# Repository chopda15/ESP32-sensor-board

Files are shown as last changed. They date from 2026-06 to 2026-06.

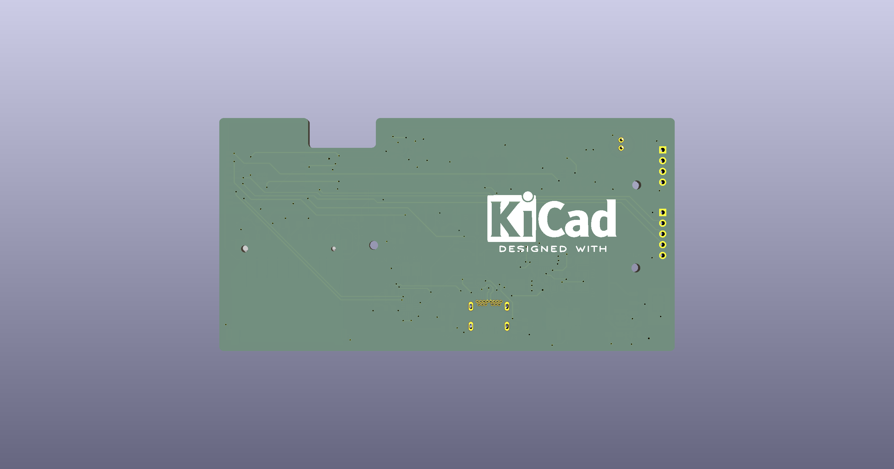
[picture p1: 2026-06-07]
3D_image/ESP32-sensor-board_3D_back.png

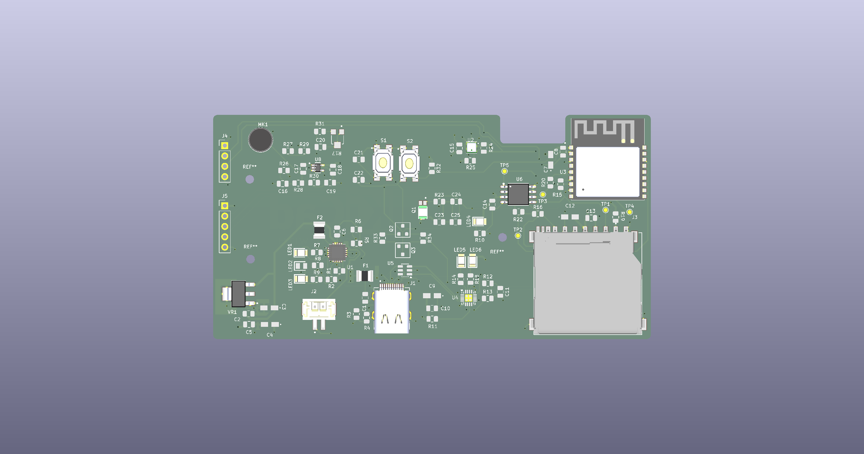
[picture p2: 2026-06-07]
3D_image/ESP32-sensor-board_3D_front.png

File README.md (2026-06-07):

# ESP32-C3 IoT Sensor Board with Li-ion Power Management

Custom-designed IoT PCB built in KiCad featuring the ESP32-C3-WROOM-02 module, integrated Li-ion charging circuitry, environmental sensing, onboard storage, and USB-C connectivity.

This project was developed to practice real-world embedded hardware design workflows including schematic capture, PCB layout, signal integrity considerations, power management, DFM validation, and manufacturing preparation.

---

# Features

## Microcontroller
- ESP32-C3-WROOM-02
- Wi-Fi + BLE connectivity
- Low-power IoT architecture

## Power System
- TP4056 Li-ion battery charger
- USB-C power input
- Single-cell LiPo battery support
- Battery charging and protection circuitry
- 3.3V regulated power rail

## Sensors & Peripherals
- BME280 environmental sensor
  - Temperature
  - Humidity
  - Pressure
- Ambient light sensor
- Sound sensor with microphone amplifier
- OLED display via I2C
- SPI flash memory
- Micro SD card interface

## User Interface
- Status LEDs
- Push buttons
- USB-UART interface for programming/debugging

---

# PCB Design Highlights

## Signal Integrity
- Differential routing for USB signals
- SPI trace optimization
- Reduced trace lengths for high-speed signals
- Ground plane implementation
- Decoupling capacitor placement optimization

## Power Distribution
- Copper pours for stable power delivery
- Wide power traces to minimize voltage drop
- Multiple decoupling capacitors for noise reduction

## Manufacturing Considerations
- ERC and DRC validation
- DFM analysis before fabrication
- Gerber generation
- BOM and centroid file generation
- Silkscreen refinement
- 3D PCB validation

---

# Tools & Technologies

- KiCad 9
- ESP32-C3
- TP4056
- JLCPCB DFM tools
- Git & GitHub

---

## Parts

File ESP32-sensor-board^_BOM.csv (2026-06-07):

Reference | Qty | Value | DNP | Exclude from BOM | Exclude from Board | Footprint | Datasheet
C1,C2,C5,C8,C10,C13,C14,C15,C16,C18,C21,C22,C23 | 13 | 0.1u |  |  |  | Capacitor_SMD:C_0805_2012Metric
C3,C4,C7,C12 | 4 | 10u |  |  |  | Footprints:T491A
C6,C11 | 2 | 1u |  |  |  | Capacitor_SMD:C_0805_2012Metric
C9 | 1 | 4.7u |  |  |  | Footprints:T491A
C17,C24,C25 | 3 | 10n |  |  |  | Capacitor_SMD:C_0805_2012Metric
C19 | 1 | 10u |  |  |  | Capacitor_SMD:C_0805_2012Metric
C20 | 1 | 100pF |  |  |  | Capacitor_SMD:C_0805_2012Metric
F1,F2 | 2 | 0ZCH0110AF2E |  |  |  | Footprints:FUSC3226X100N | https://www.belfuse.com/resources/datasheets/circuitprotection/ds-cp-0zch-series.pdf
J1 | 1 | SS-52400-002 |  |  |  | Footprints:BELFUSE_SS-52400-002
J2 | 1 | B2B-PH-SM4-TB |  |  |  | Footprints:JST_B2B-PH-SM4-TB
J3 | 1 | GSD090012SEU |  |  |  | Footprints:AMPHENOL_GSD090012SEU
J4 | 1 | Conn_01x04_Pin |  |  |  | Connector_PinHeader_2.54mm:PinHeader_1x04_P2.54mm_Vertical
J5 | 1 | Conn_01x05_Pin |  |  |  | Connector_PinHeader_2.54mm:PinHeader_1x05_P2.54mm_Vertical
LED1,LED4,LED5 | 3 | LTST-C170KRKT |  |  |  | Footprints:LEDC2012X120N | https://componentsearchengine.com/Datasheets/1/LTST-C170KRKT.pdf
LED2,LED6 | 2 | LTST-C170GKT |  |  |  | Footprints:LEDC2012X120N | https://mm.digikey.com/Volume0/opasdata/d220001/medias/docus/895/LTST-C170GKT.pdf
LED3 | 1 | LTST-C170TBKT |  |  |  | Footprints:LEDC2012X120N | https://componentsearchengine.com/Datasheets/1/LTST-C170TBKT.pdf
MK1 | 1 | CMC-5042PF-AC |  |  |  | Footprints:CUI_CMC-5042PF-AC
Q1 | 1 | TEMT6000X01 |  |  |  | Footprints:TRANS_TEMT6000X01
Q2,Q3 | 2 | BC817 |  |  |  | PCM_Package_TO_SOT_SMD_AKL:SOT-23 | https://www.tme.eu/Document/7b5ea7386544f524d0315334956093bb/BC817-16.215.pdf
R1,R2,R6,R19,R23,R32,R33,R34 | 8 | 10K |  |  |  | Resistor_SMD:R_0805_2012Metric
R3,R4 | 2 | 5.1K |  |  |  | Resistor_SMD:R_0805_2012Metric
R5,R26 | 2 | 2K |  |  |  | Resistor_SMD:R_0805_2012Metric
R7,R8,R9,R10,R14,R18 | 6 | 470 |  |  |  | Resistor_SMD:R_0805_2012Metric
R11,R30 | 2 | 1K |  |  |  | Resistor_SMD:R_0805_2012Metric
R12 | 1 | 47K5 |  |  |  | Resistor_SMD:R_0805_2012Metric
R13 | 1 | 22K1 |  |  |  | Resistor_SMD:R_0805_2012Metric
R15,R16,R20,R22 | 4 | 50 |  |  |  | Resistor_SMD:R_0805_2012Metric
R17 | 1 | 35WR100KLFTR |  |  |  | Footprints:TRIM_35WR100KLFTR
R24,R25 | 2 | 4K7 |  |  |  | Resistor_SMD:R_0805_2012Metric
R27,R28,R29 | 3 | 1M |  |  |  | Resistor_SMD:R_0805_2012Metric
R31 | 1 | 22K |  |  |  | Resistor_SMD:R_0805_2012Metric
S1,S2 | 2 | USLPT2819DT2TR |  |  |  | Footprints:SW_TL3305AF260QG
TP1 | 1 | TestMosi_DI |  |  |  | TestPoint:TestPoint_Pad_D1.0mm
TP2 | 1 | TestMiso_DI |  |  |  | TestPoint:TestPoint_Pad_D1.0mm
TP3 | 1 | Test SCLK |  |  |  | TestPoint:TestPoint_Pad_D1.0mm
TP4 | 1 | Test CS_SD |  |  |  | TestPoint:TestPoint_Pad_D1.0mm
TP5 | 1 | Test CS |  |  |  | TestPoint:TestPoint_Pad_D1.0mm
U1 | 1 | MCP73871-2CAI_ML |  |  |  | Footprints:QFN50P400X400X100-21N
U2 | 1 | BME280 |  |  |  | Footprints:PSON65P250X250X100-8N
U3 | 1 | ESP32-C3-WROOM-02-H4 |  |  |  | Footprints:MODULE_ESP32-C3-WROOM-02-H4
U4 | 1 | CP2102N-Axx-xQFN20 |  |  |  | Package_DFN_QFN:SiliconLabs_QFN-20-1EP_3x3mm_P0.5mm_EP1.8x1.8mm | https://www.silabs.com/documents/public/data-sheets/cp2102n-datasheet.pdf
U5 | 1 | USBLC6-2SC6 |  |  |  | Package_TO_SOT_SMD:SOT-23-6 | https://www.st.com/resource/en/datasheet/usblc6-2.pdf
U6 | 1 | W25Q32JVSSIQ |  |  |  | Footprints:SOIC127P790X216-8N
U8 | 1 | MAX4466EXK |  |  |  | Footprints:SOT65P210X110-5N
VR1 | 1 | LM1117MPX-3.3 |  |  |  | Footprints:VREG_LM1117MPX-3.3_NOPB

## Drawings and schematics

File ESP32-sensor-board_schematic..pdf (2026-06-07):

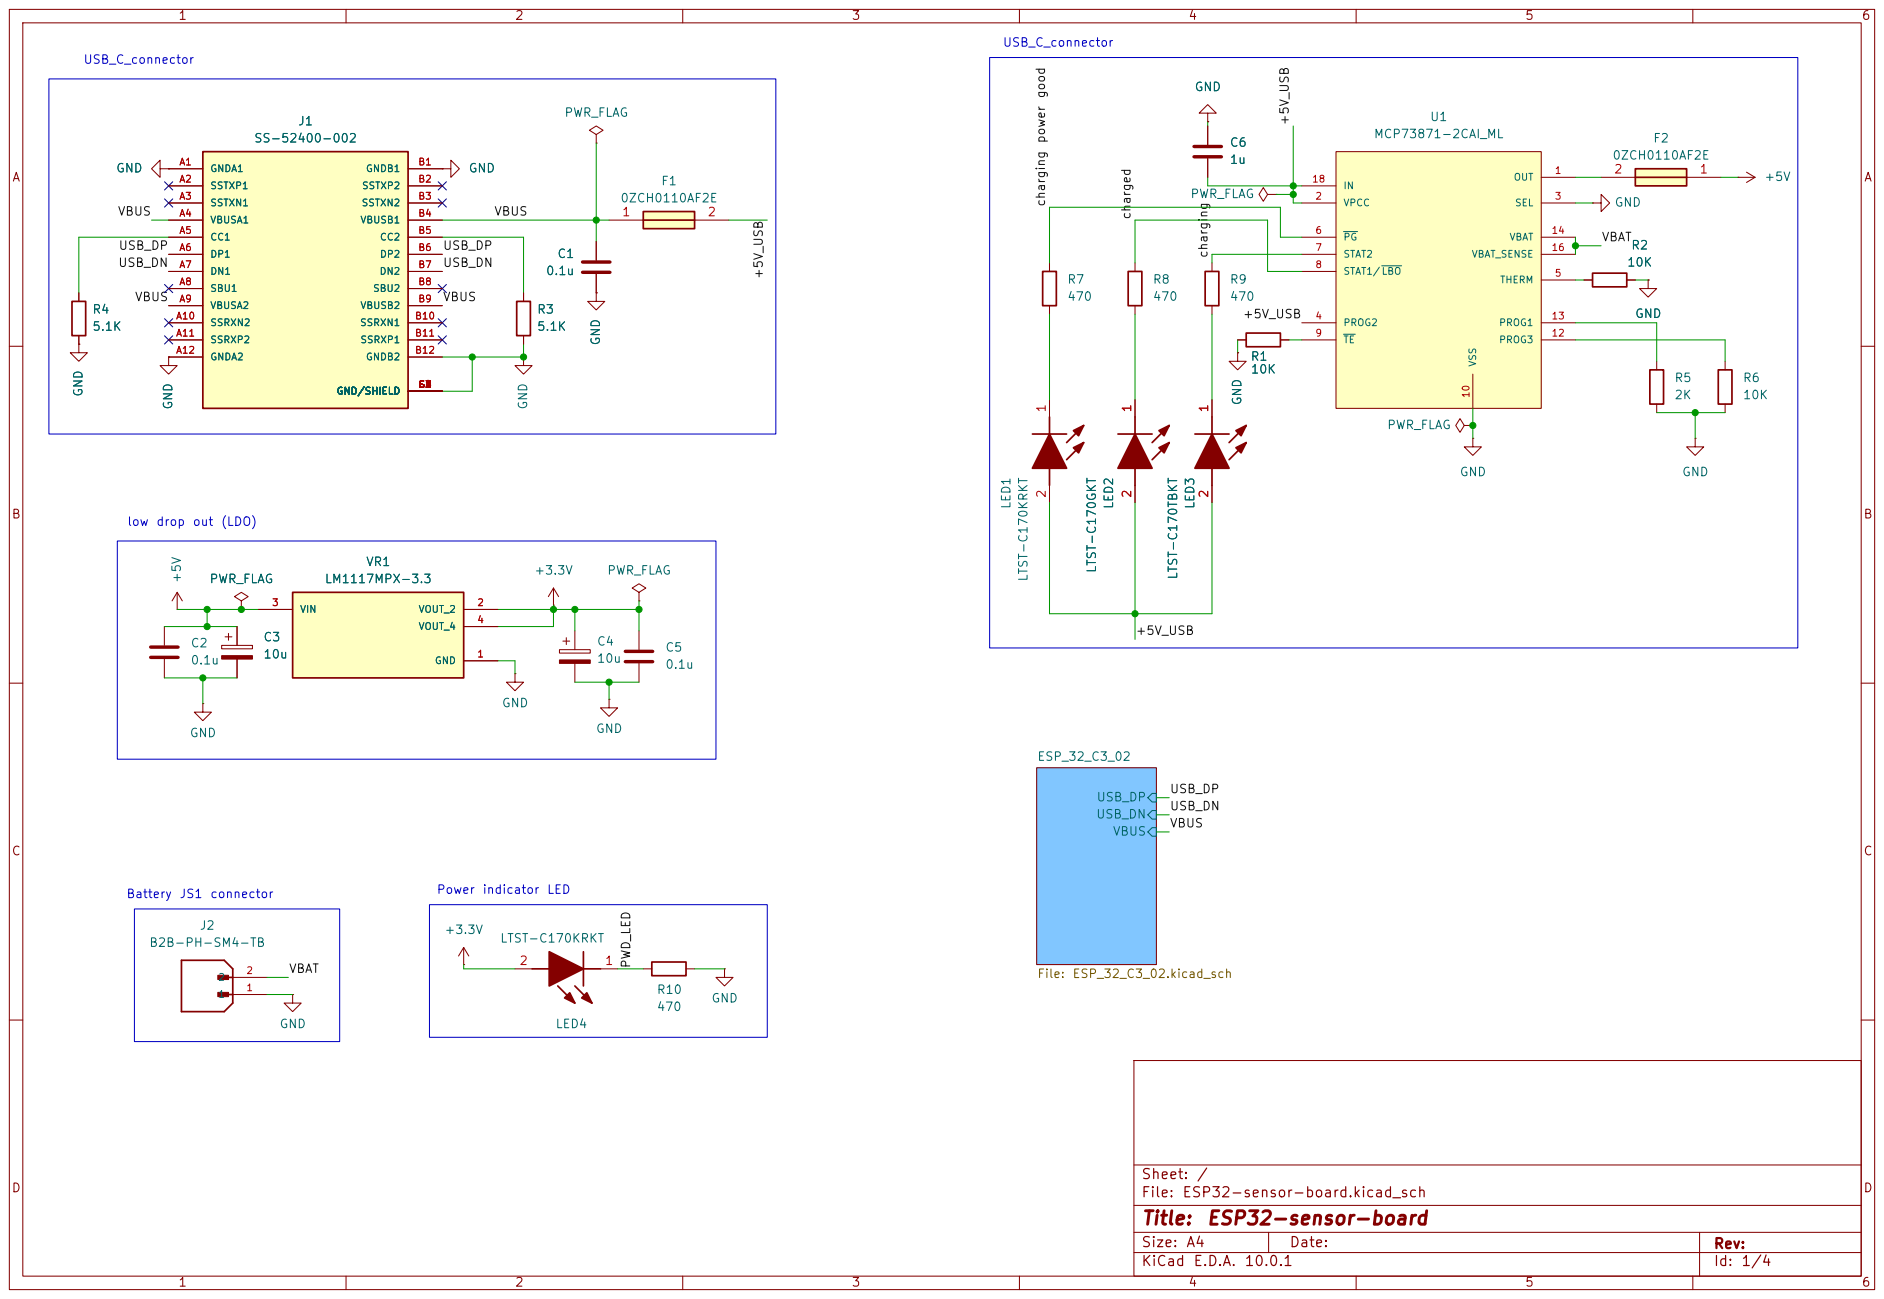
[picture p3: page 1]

low drop out (LDO) USB_C_connector Battery JS1 connector GND

VBUS Power indicator LED

Size: A4 | Rev:
KiCad E.D.A. 10.0.1 | Id: 1/4

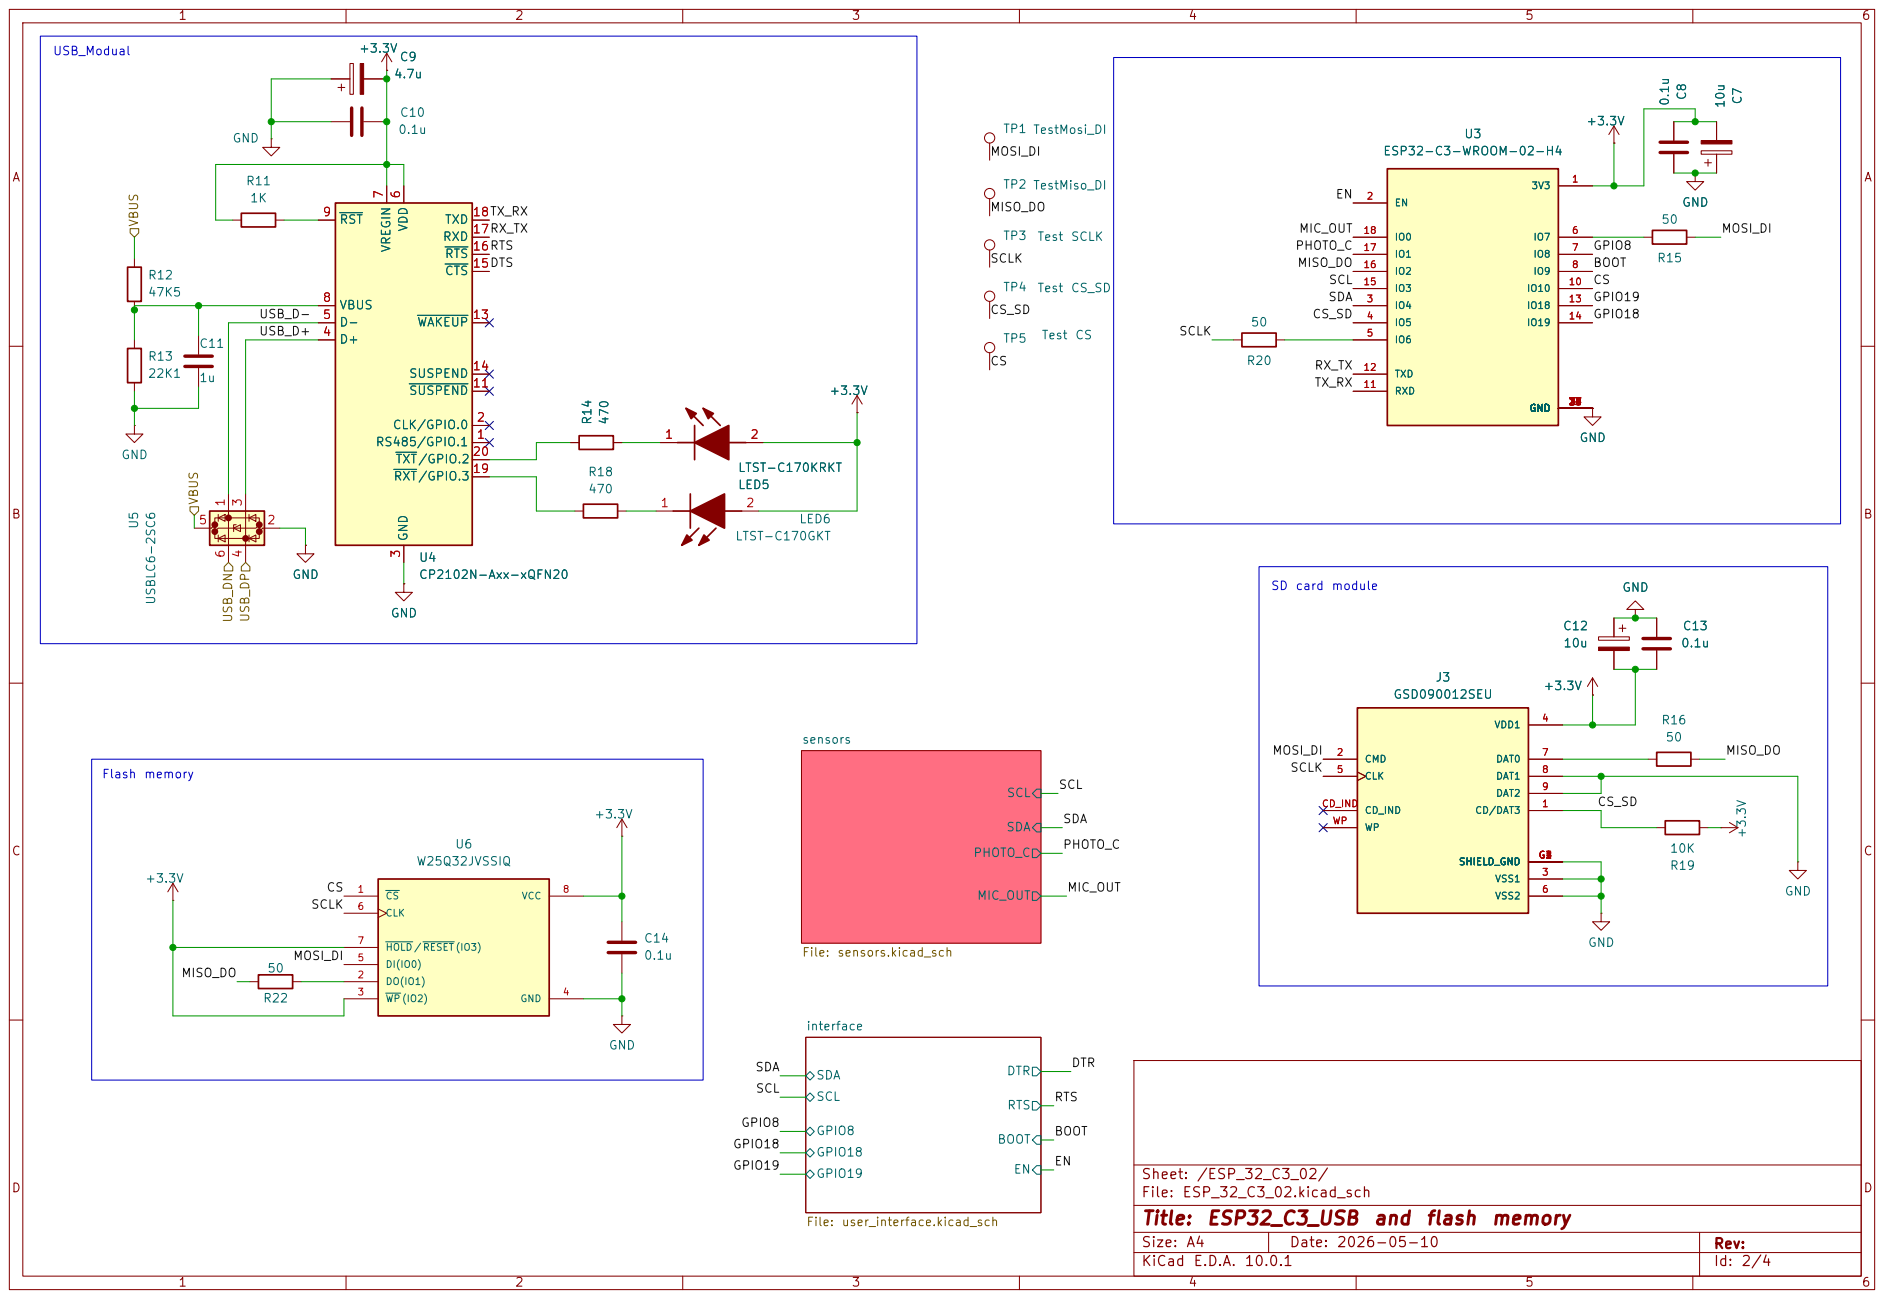
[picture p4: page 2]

Sheet: /ESP_32_C3_02/
File: ESP_32_C3_02.kicad_sch
Title: ESP32_C3_USB and flash memory

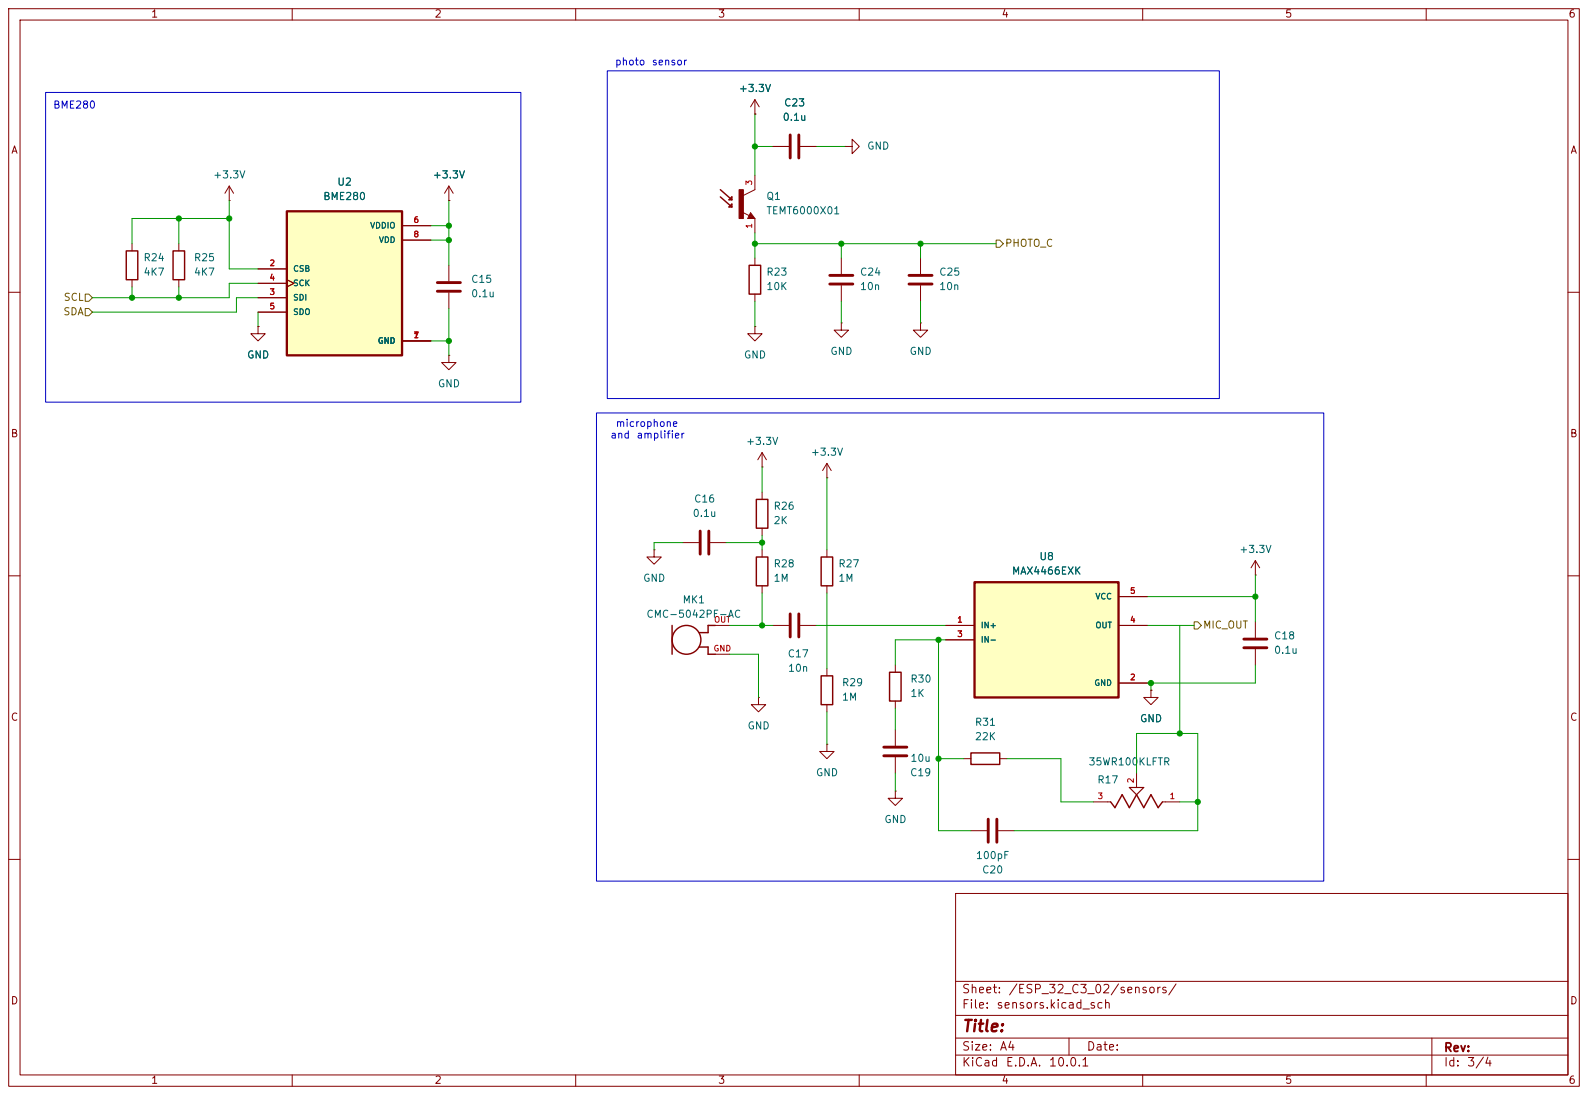
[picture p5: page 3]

GND OUT MK1 CMC-5042PF-AC +3.3V GND

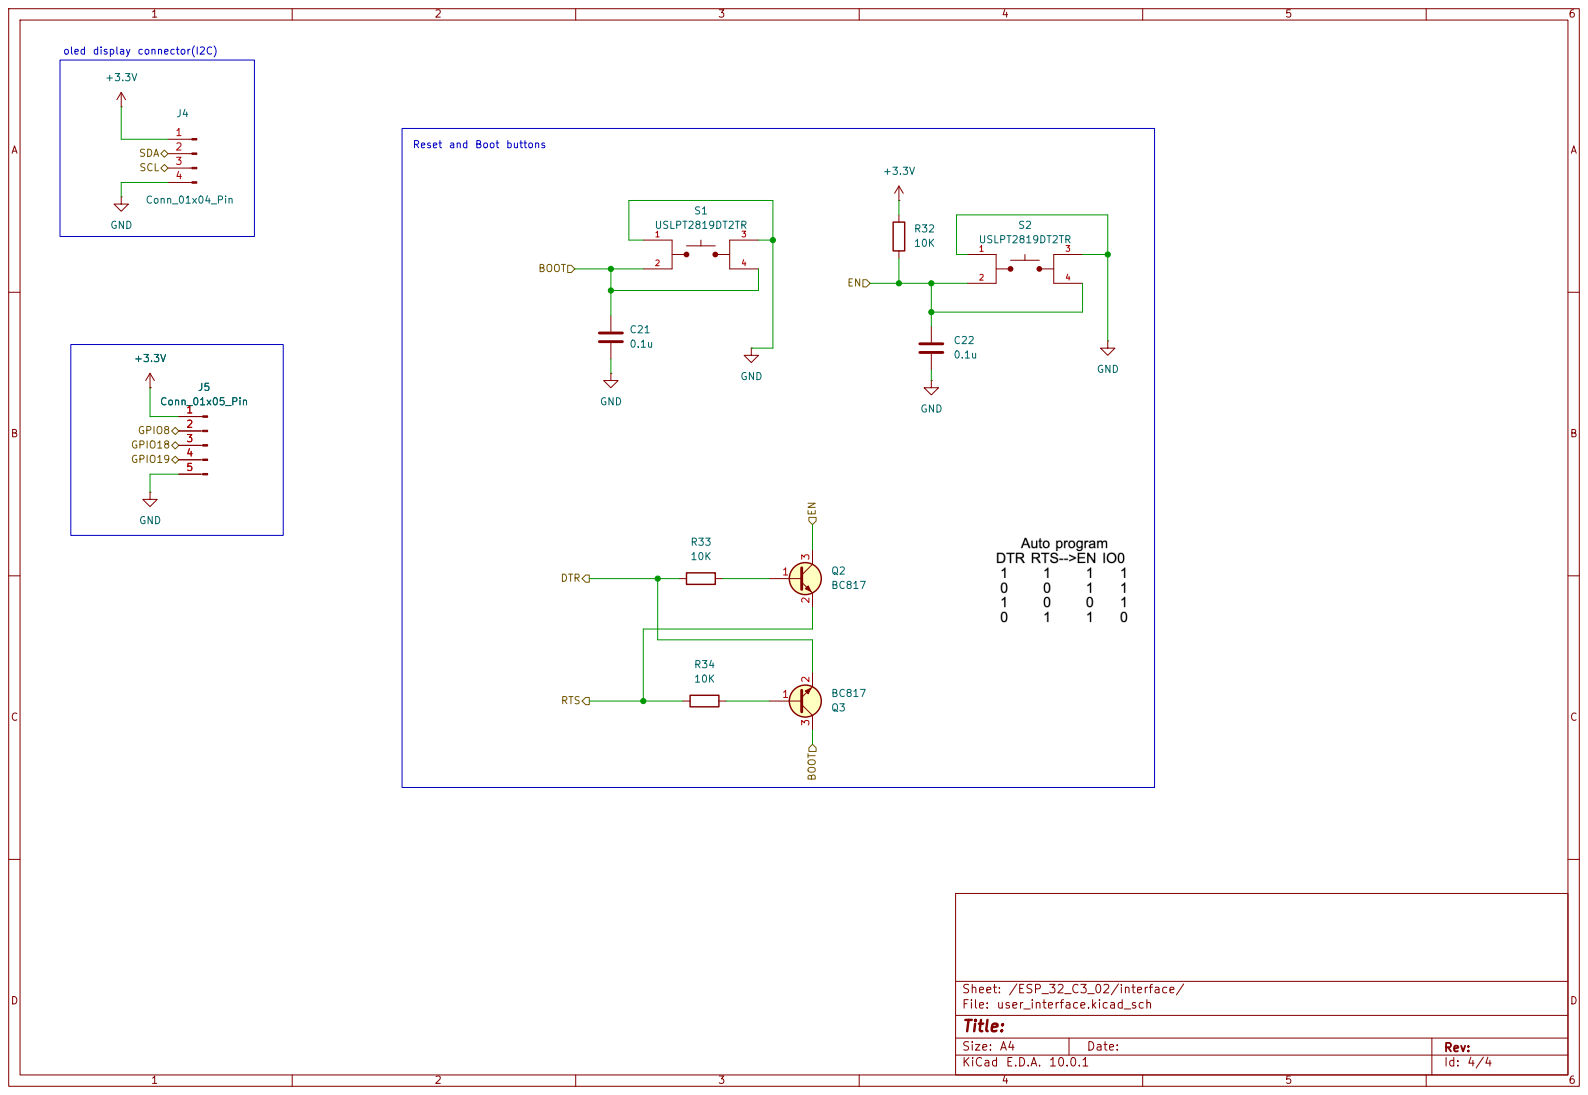
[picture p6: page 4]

Reset and Boot buttons oled display connector(I2C) J5 Conn_01x05_Pin 1

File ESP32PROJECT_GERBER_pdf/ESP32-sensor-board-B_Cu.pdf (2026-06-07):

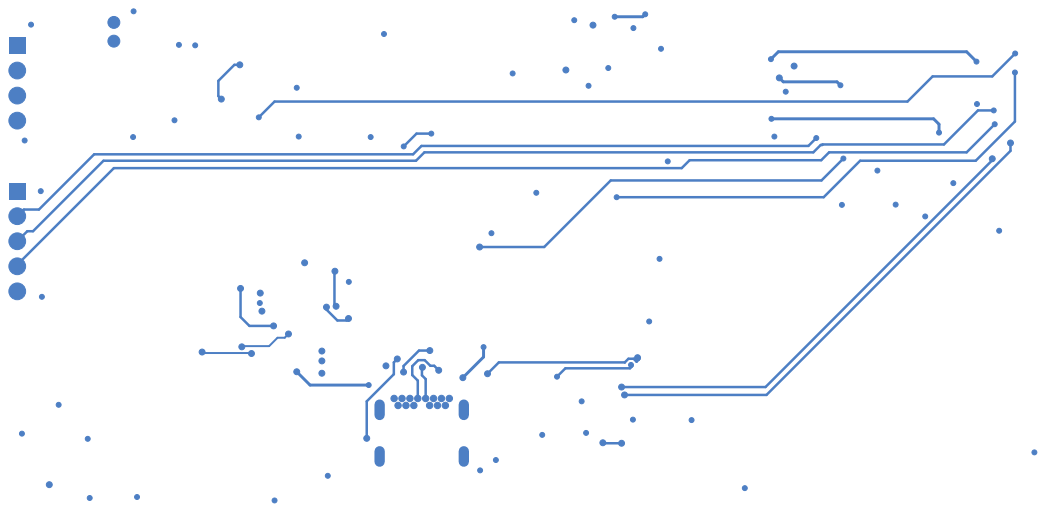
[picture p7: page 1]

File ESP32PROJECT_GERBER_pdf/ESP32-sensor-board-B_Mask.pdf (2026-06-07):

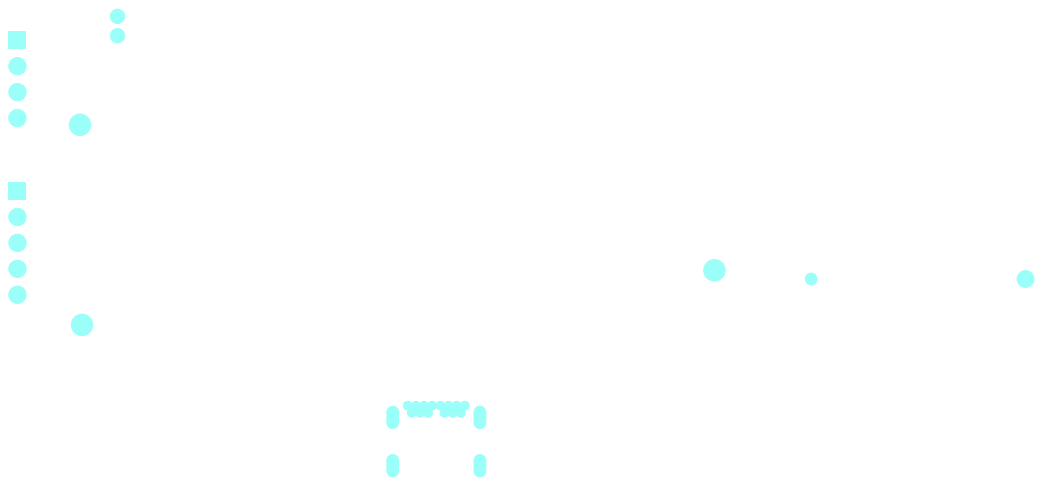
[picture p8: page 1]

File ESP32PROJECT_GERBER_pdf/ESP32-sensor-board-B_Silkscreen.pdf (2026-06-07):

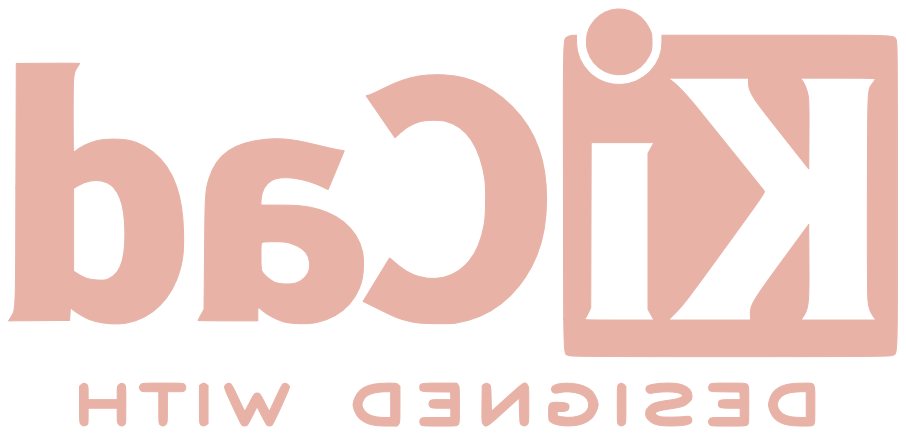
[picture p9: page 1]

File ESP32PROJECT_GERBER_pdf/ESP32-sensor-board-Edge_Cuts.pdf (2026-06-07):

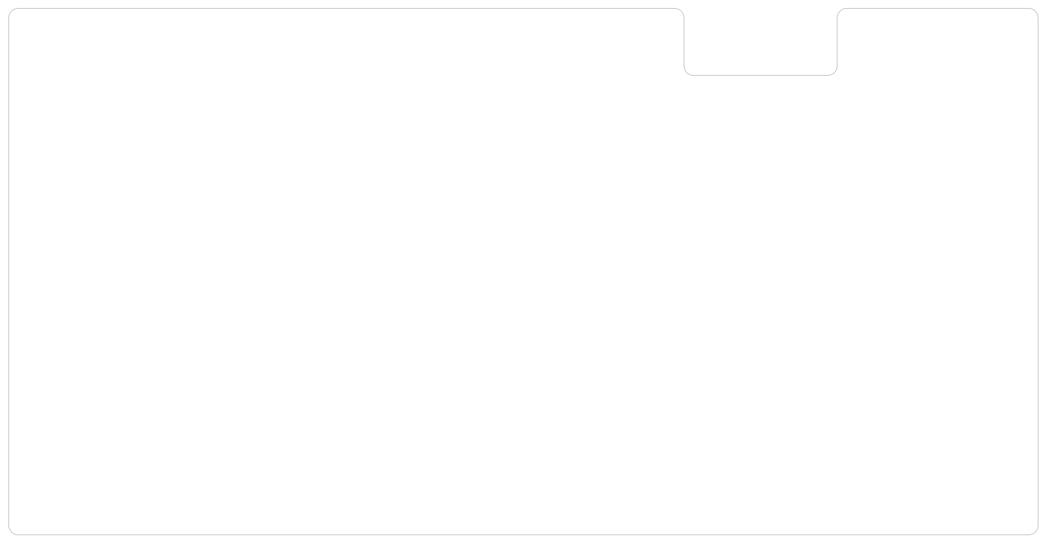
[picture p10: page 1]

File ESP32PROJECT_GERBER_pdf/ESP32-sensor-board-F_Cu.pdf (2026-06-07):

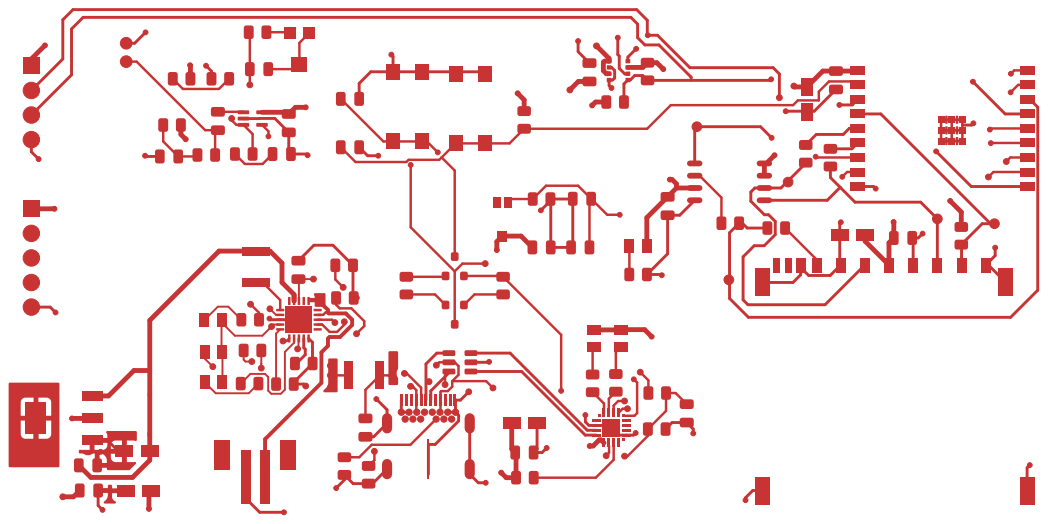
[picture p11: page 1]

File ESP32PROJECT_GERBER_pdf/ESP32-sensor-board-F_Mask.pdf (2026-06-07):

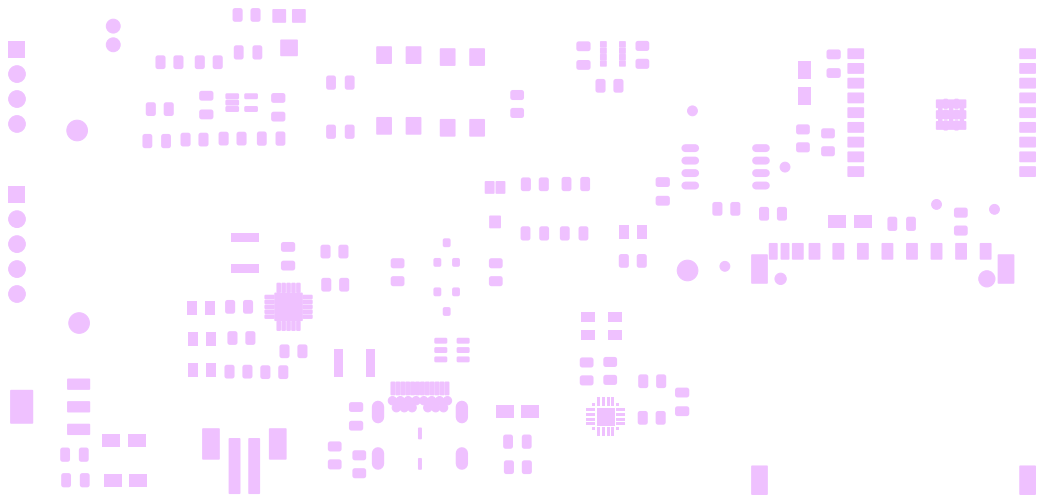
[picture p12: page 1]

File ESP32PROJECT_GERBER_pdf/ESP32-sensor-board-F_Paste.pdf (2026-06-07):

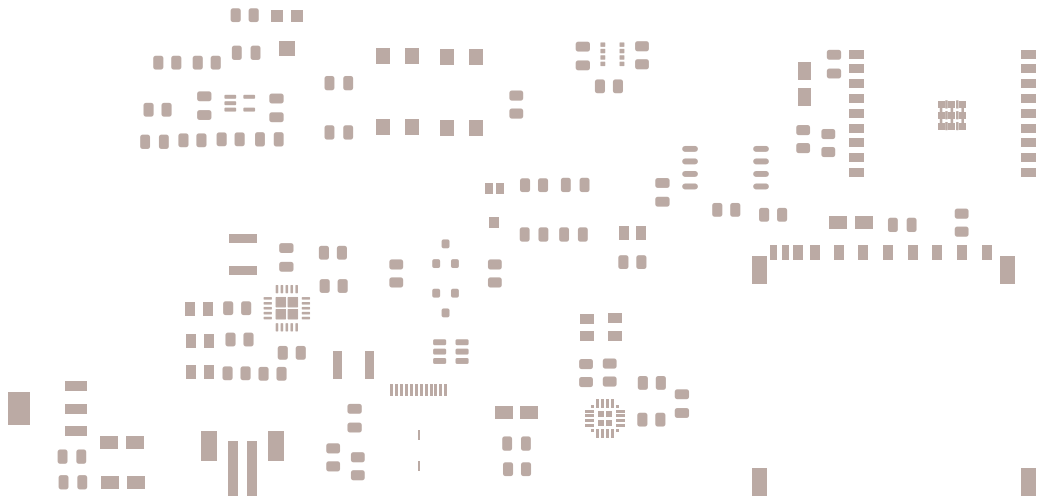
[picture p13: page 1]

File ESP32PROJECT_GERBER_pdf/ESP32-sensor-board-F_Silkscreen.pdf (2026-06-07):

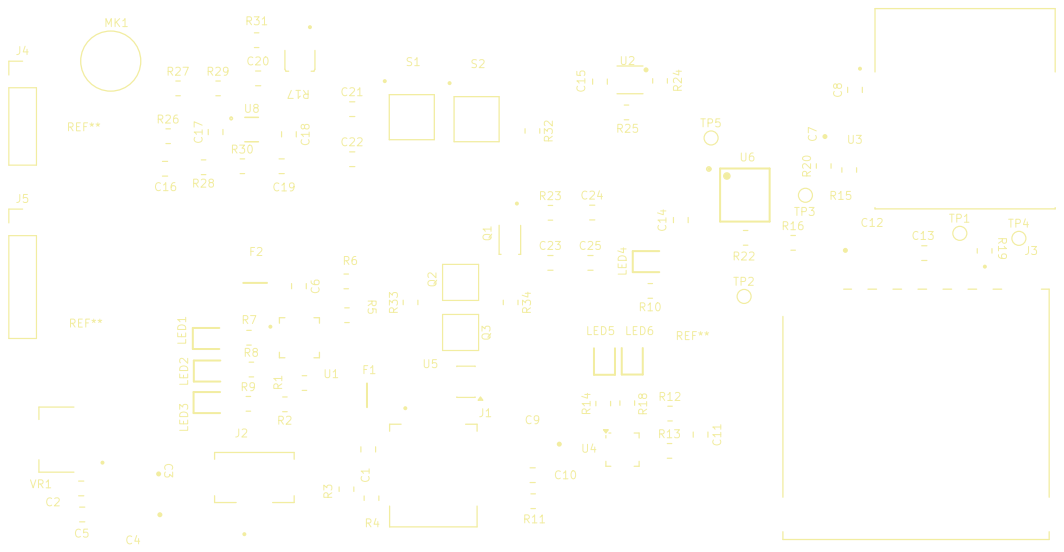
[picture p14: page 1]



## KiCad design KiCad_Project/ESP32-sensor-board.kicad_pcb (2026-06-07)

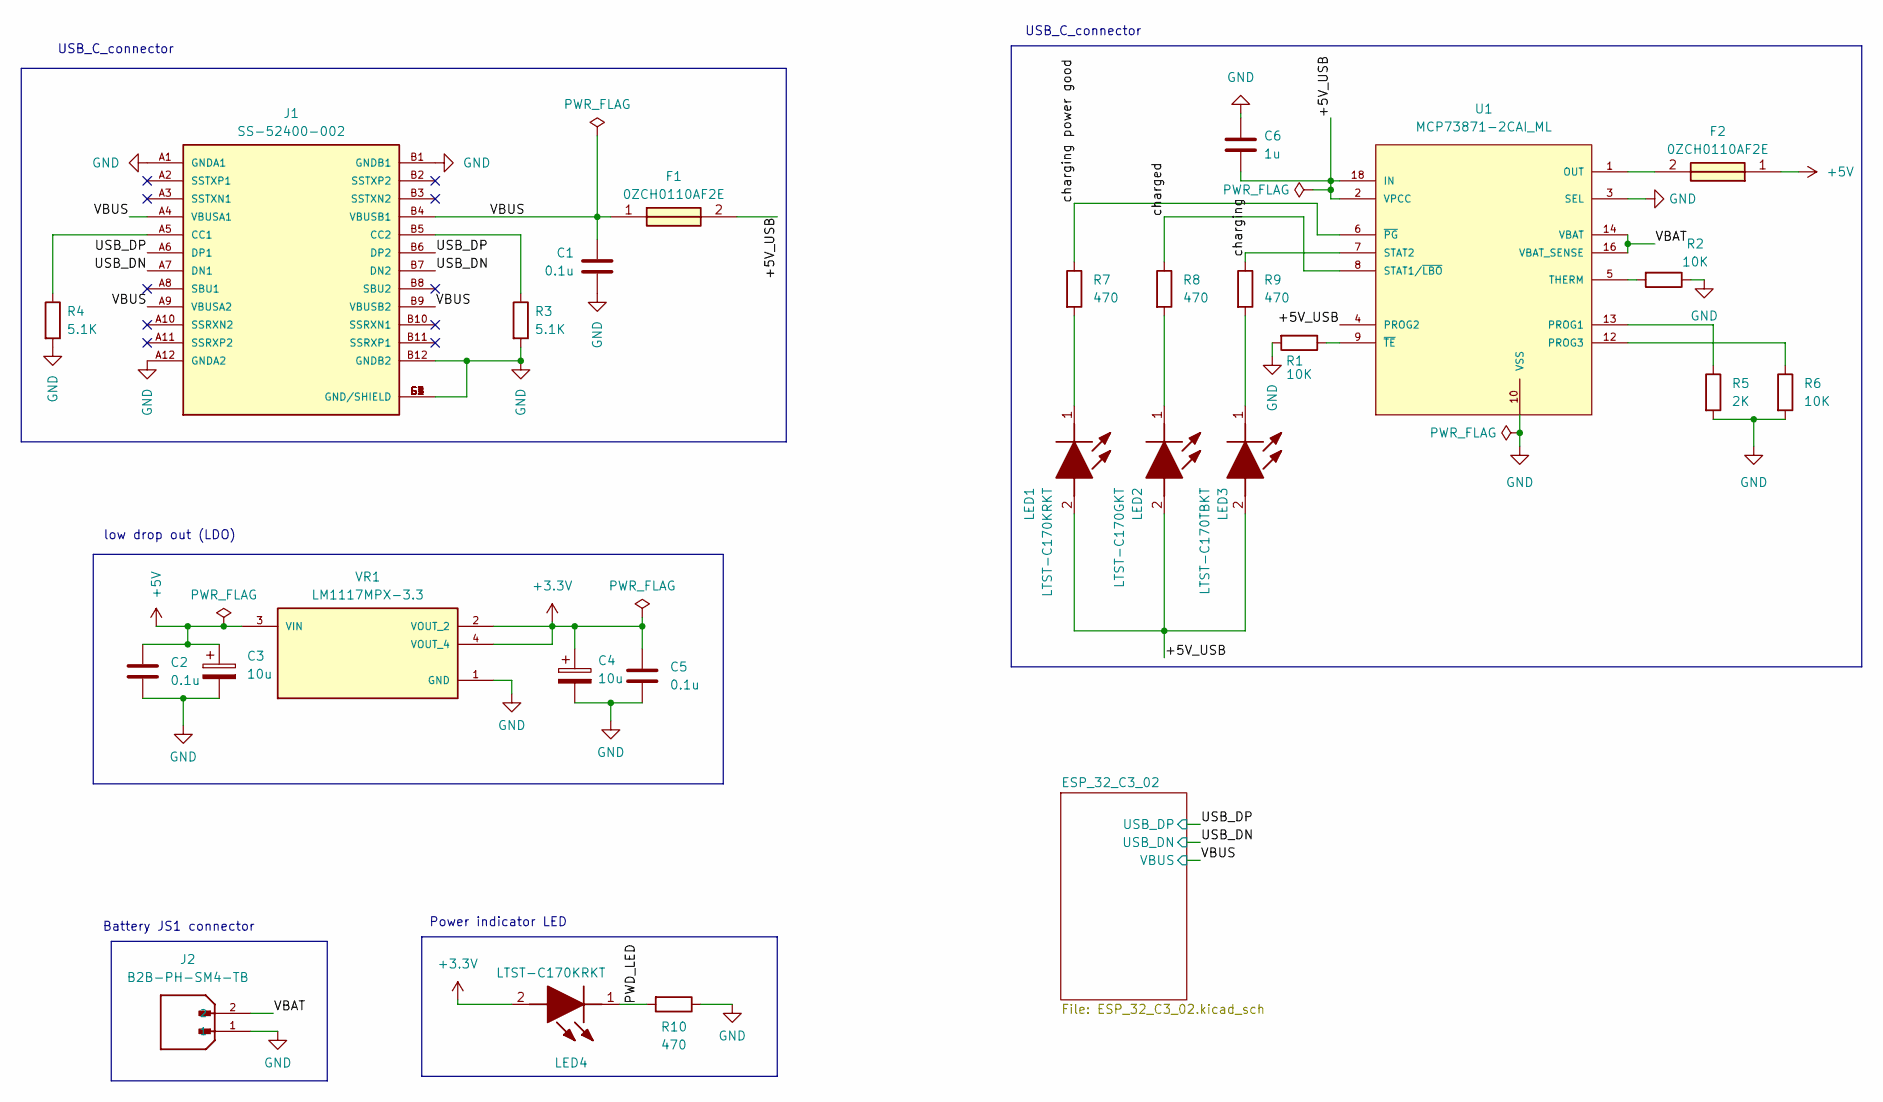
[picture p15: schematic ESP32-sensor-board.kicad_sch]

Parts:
C1, C2, C5: 0.1u; C_0805_2012Metric
C3, C4: 10u; T491A
C6: 1u; C_0805_2012Metric
F1, F2: 0ZCH0110AF2E; FUSC3226X100N; Manufacturer_Part_Number 0ZCH0110AF2E
J1: SS-52400-002; BELFUSE_SS-52400-002; PARTREV A0
J2: B2B-PH-SM4-TB; JST_B2B-PH-SM4-TB; PARTREV N/A
LED1, LED4: LTST-C170KRKT; LEDC2012X120N; Manufacturer_Part_Number LTST-C170KRKT; Mouser Part Number 859-LTST-C170KRKT
LED2: LTST-C170GKT; LEDC2012X120N; Manufacturer_Part_Number LTST-C170GKT; Mouser Part Number 859-LTST-C170GKT
LED3: LTST-C170TBKT; LEDC2012X120N; Manufacturer_Part_Number LTST-C170TBKT; Mouser Part Number 859-LTST-C170TBKT
R1, R2, R6: 10K; R_0805_2012Metric
R3, R4: 5.1K; R_0805_2012Metric
R5: 2K; R_0805_2012Metric
R7, R8, R9, R10: 470; R_0805_2012Metric
U1: MCP73871-2CAI_ML; QFN50P400X400X100-21N; PARTREV D
VR1: LM1117MPX-3.3; VREG_LM1117MPX-3.3_NOPB

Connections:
+3.3V: C4.1, C5.1, LED4.2 (A), VR1.2 (VOUT_2), VR1.4 (VOUT_4); also elsewhere on the board
+5V: C2.1, C3.1, F2.1, U1.19, VR1.3 (VIN)
/+5V_USB: C6.2, F1.2, LED1.2 (A), LED2.2 (A), LED3.2 (A), U1.2 (VPCC), U1.4 (PROG2), U1.18 (IN)
/PWD_LED: LED4.1 (K), R10.2
/USB_DN: J1.A7 (DN1), J1.B7 (DN2); also elsewhere on the board
/USB_DP: J1.A6 (DP1), J1.B6 (DP2); also elsewhere on the board
/VBAT: J2.2, U1.14 (VBAT), U1.16 (VBAT_SENSE)
/VBUS: C1.1, F1.1, J1.A4 (VBUSA1), J1.A9 (VBUSA2), J1.B4 (VBUSB1), J1.B9 (VBUSB2); also elsewhere on the board
/charged: R8.1, U1.8 (STAT1/~LBO)
/charging: R9.1, U1.7 (STAT2)
/charging power good: R7.1, U1.6 (~PG)
GND: C1.2, C2.2, C3.2, C4.2, C5.2, C6.1, J1.A1 (GNDA1), J1.A12 (GNDA2), J1.B1 (GNDB1), J1.B12 (GNDB2), J1.G1 (GND/SHIELD), J1.G2 (GND/SHIELD), J1.G3 (GND/SHIELD), J1.G4 (GND/SHIELD), J1.S1 (GND/SHIELD), J1.S2 (GND/SHIELD), J1.S3 (GND/SHIELD), J1.S4 (GND/SHIELD), J2.1, R1.2, R2.1, R3.2, R4.2, R5.2, R6.2, R10.1, U1.3 (SEL), U1.10 (VSS), U1.21, VR1.1 (GND); also elsewhere on the board
unnamed: J1.A5 (CC1), R4.1
unnamed: J1.B5 (CC2), R3.1
unnamed: LED1.1 (K), R7.2
unnamed: LED2.1 (K), R8.2
unnamed: LED3.1 (K), R9.2
unnamed: F2.2, U1.1 (OUT)
unnamed: R5.1, U1.13 (PROG1)
unnamed: R6.1, U1.12 (PROG3)
unnamed: R2.2, U1.5 (THERM)
unnamed: R1.1, U1.9 (~TE)

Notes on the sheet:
USB_C_connector
Battery JS1 connector
low drop out (LDO)
Power indicator LED

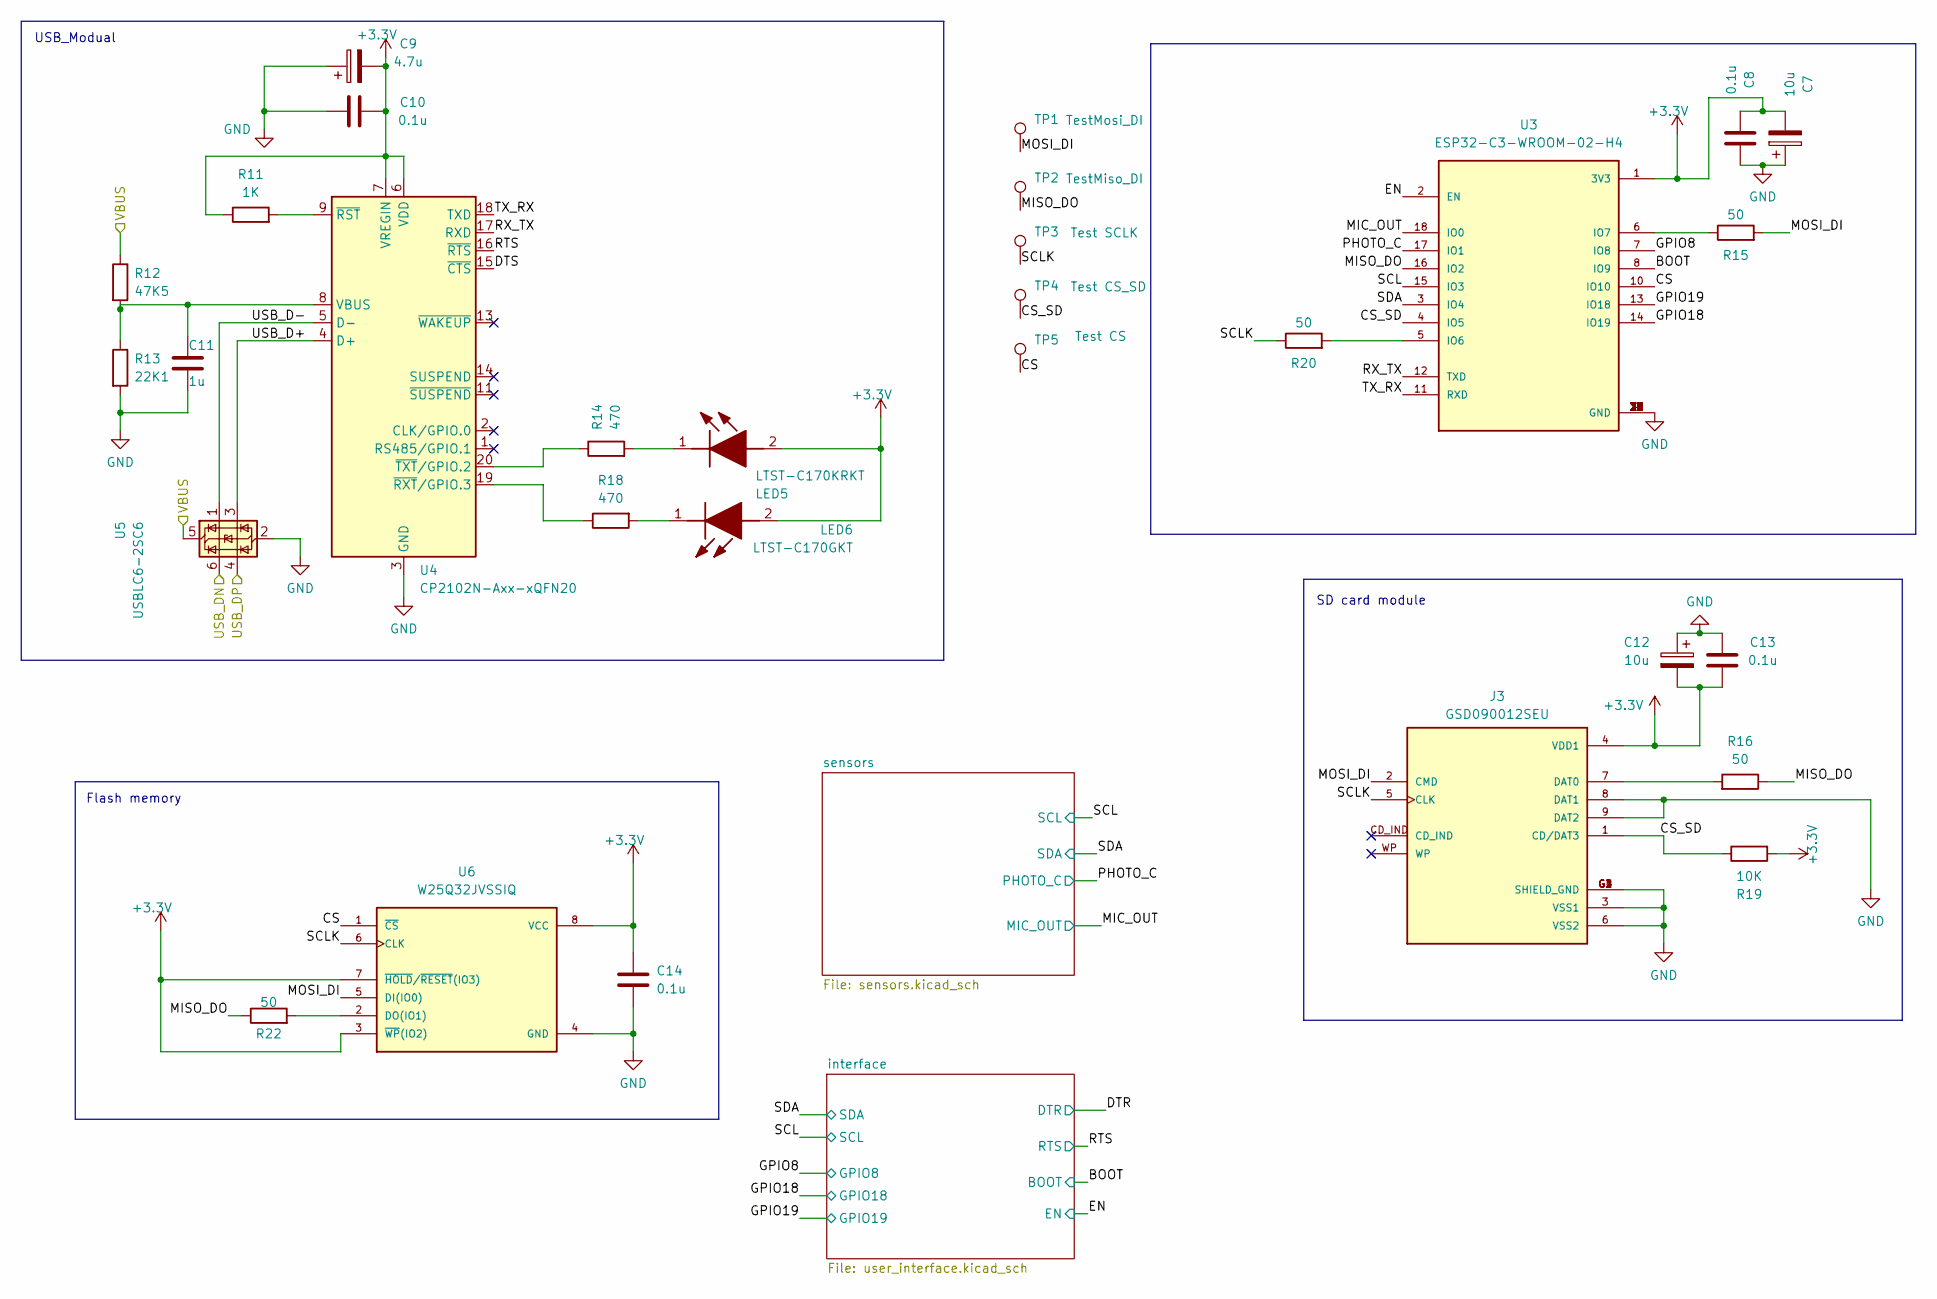
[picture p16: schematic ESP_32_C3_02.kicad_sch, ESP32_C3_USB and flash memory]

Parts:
C7, C12: 10u; T491A
C8, C10, C13, C14: 0.1u; C_0805_2012Metric
C9: 4.7u; T491A
C11: 1u; C_0805_2012Metric
J3: GSD090012SEU; AMPHENOL_GSD090012SEU; PARTREV E
LED5: LTST-C170KRKT; LEDC2012X120N; Manufacturer_Part_Number LTST-C170KRKT; Mouser Part Number 859-LTST-C170KRKT
LED6: LTST-C170GKT; LEDC2012X120N; Manufacturer_Part_Number LTST-C170GKT; Mouser Part Number 859-LTST-C170GKT
R11: 1K; R_0805_2012Metric
R12: 47K5; R_0805_2012Metric
R13: 22K1; R_0805_2012Metric
R14, R18: 470; R_0805_2012Metric
R15, R16, R20, R22: 50; R_0805_2012Metric
R19: 10K; R_0805_2012Metric
TP1: TestMosi_DI; TestPoint_Pad_D1.0mm
TP2: TestMiso_DI; TestPoint_Pad_D1.0mm
TP3: Test SCLK; TestPoint_Pad_D1.0mm
TP4: Test CS_SD; TestPoint_Pad_D1.0mm
TP5: Test CS; TestPoint_Pad_D1.0mm
U3: ESP32-C3-WROOM-02-H4; MODULE_ESP32-C3-WROOM-02-H4
U4: CP2102N-Axx-xQFN20; SiliconLabs_QFN-20-1EP_3x3mm_P0.5mm_EP1.8x1.8mm
U5: USBLC6-2SC6; SOT-23-6
U6: W25Q32JVSSIQ; SOIC127P790X216-8N; M_PART_NUMBER W25QXX

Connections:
+3.3V: C7.2, C8.2, C9.2, C10.2, C12.2, C13.2, C14.1, J3.4 (VDD1), LED5.2 (A), LED6.2 (A), R11.1, R19.2, U3.1 (3V3), U4.6 (VDD), U4.7 (VREGIN), U6.3 (~WP(IO2)), U6.7 (~HOLD/~RESET(IO3)), U6.8 (VCC); also elsewhere on the board
/ESP_32_C3_02/BOOT: U3.8 (IO9); also elsewhere on the board
/ESP_32_C3_02/CS: TP5.1 (1_1), U3.10 (IO10), U6.1 (~CS)
/ESP_32_C3_02/CS_SD: J3.1 (CD/DAT3), R19.1, TP4.1 (1_1), U3.4 (IO5)
/ESP_32_C3_02/DTS: U4.15 (~CTS)
/ESP_32_C3_02/EN: U3.2 (EN); also elsewhere on the board
/ESP_32_C3_02/GPIO8: U3.7 (IO8); also elsewhere on the board
/ESP_32_C3_02/GPIO18: U3.14 (IO19); also elsewhere on the board
/ESP_32_C3_02/GPIO19: U3.13 (IO18); also elsewhere on the board
/ESP_32_C3_02/MIC_OUT: U3.18 (IO0); also elsewhere on the board
/ESP_32_C3_02/MISO_DO: R16.1, R22.1, TP2.1 (1_1), U3.16 (IO2)
/ESP_32_C3_02/MOSI_DI: J3.2 (CMD), R15.2, TP1.1 (1_1), U6.5 (DI(IO0))
/ESP_32_C3_02/PHOTO_C: U3.17 (IO1); also elsewhere on the board
/ESP_32_C3_02/RTS: U4.16 (~RTS); also elsewhere on the board
/ESP_32_C3_02/RX_TX: U3.12 (TXD), U4.17 (RXD)
/ESP_32_C3_02/SCL: U3.15 (IO3); also elsewhere on the board
/ESP_32_C3_02/SCLK: J3.5 (CLK), R20.1, TP3.1 (1_1), U6.6 (CLK)
/ESP_32_C3_02/SDA: U3.3 (IO4); also elsewhere on the board
/ESP_32_C3_02/TX_RX: U3.11 (RXD), U4.18 (TXD)
/ESP_32_C3_02/USB_D+: U4.4 (D+), U5.3 (I/O2)
/ESP_32_C3_02/USB_D-: U4.5 (D-), U5.1 (I/O1)
/USB_DN: U5.6 (I/O1); also elsewhere on the board
/USB_DP: U5.4 (I/O2); also elsewhere on the board
/VBUS: R12.1, U5.5 (VBUS); also elsewhere on the board
GND: C7.1, C8.1, C9.1, C10.1, C11.2, C12.1, C13.1, C14.2, J3.3 (VSS1), J3.6 (VSS2), J3.8 (DAT1), J3.9 (DAT2), J3.G1 (SHIELD_GND), J3.G2 (SHIELD_GND), J3.G3 (SHIELD_GND), J3.G4 (SHIELD_GND), R13.2, U3.9 (GND), U3.19 (GND), U3.20 (GND), U3.21 (GND), U3.22 (GND), U3.23 (GND), U3.24 (GND), U3.25 (GND), U3.26 (GND), U3.27 (GND), U3.28 (GND), U3.29 (GND), U3.30 (GND), U3.31 (GND), U3.32 (GND), U3.33 (GND), U3.34 (GND), U3.35 (GND), U3.36 (GND), U3.37 (GND), U3.38 (GND), U3.39 (GND), U4.3 (GND), U4.12 (GND), U4.21 (GND), U5.2 (GND), U6.4 (GND); also elsewhere on the board
unnamed: J3.7 (DAT0), R16.2
unnamed: LED5.1 (K), R14.2
unnamed: LED6.1 (K), R18.2
unnamed: R20.2, U3.5 (IO6)
unnamed: R15.1, U3.6 (IO7)
unnamed: C11.1, R12.2, R13.1, U4.8 (VBUS)
unnamed: R11.2, U4.9 (~RST)
unnamed: R18.1, U4.19 (~RXT/GPIO.3)
unnamed: R14.1, U4.20 (~TXT/GPIO.2)
unnamed: R22.2, U6.2 (DO(IO1))

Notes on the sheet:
USB_Modual
SD card module
Flash memory

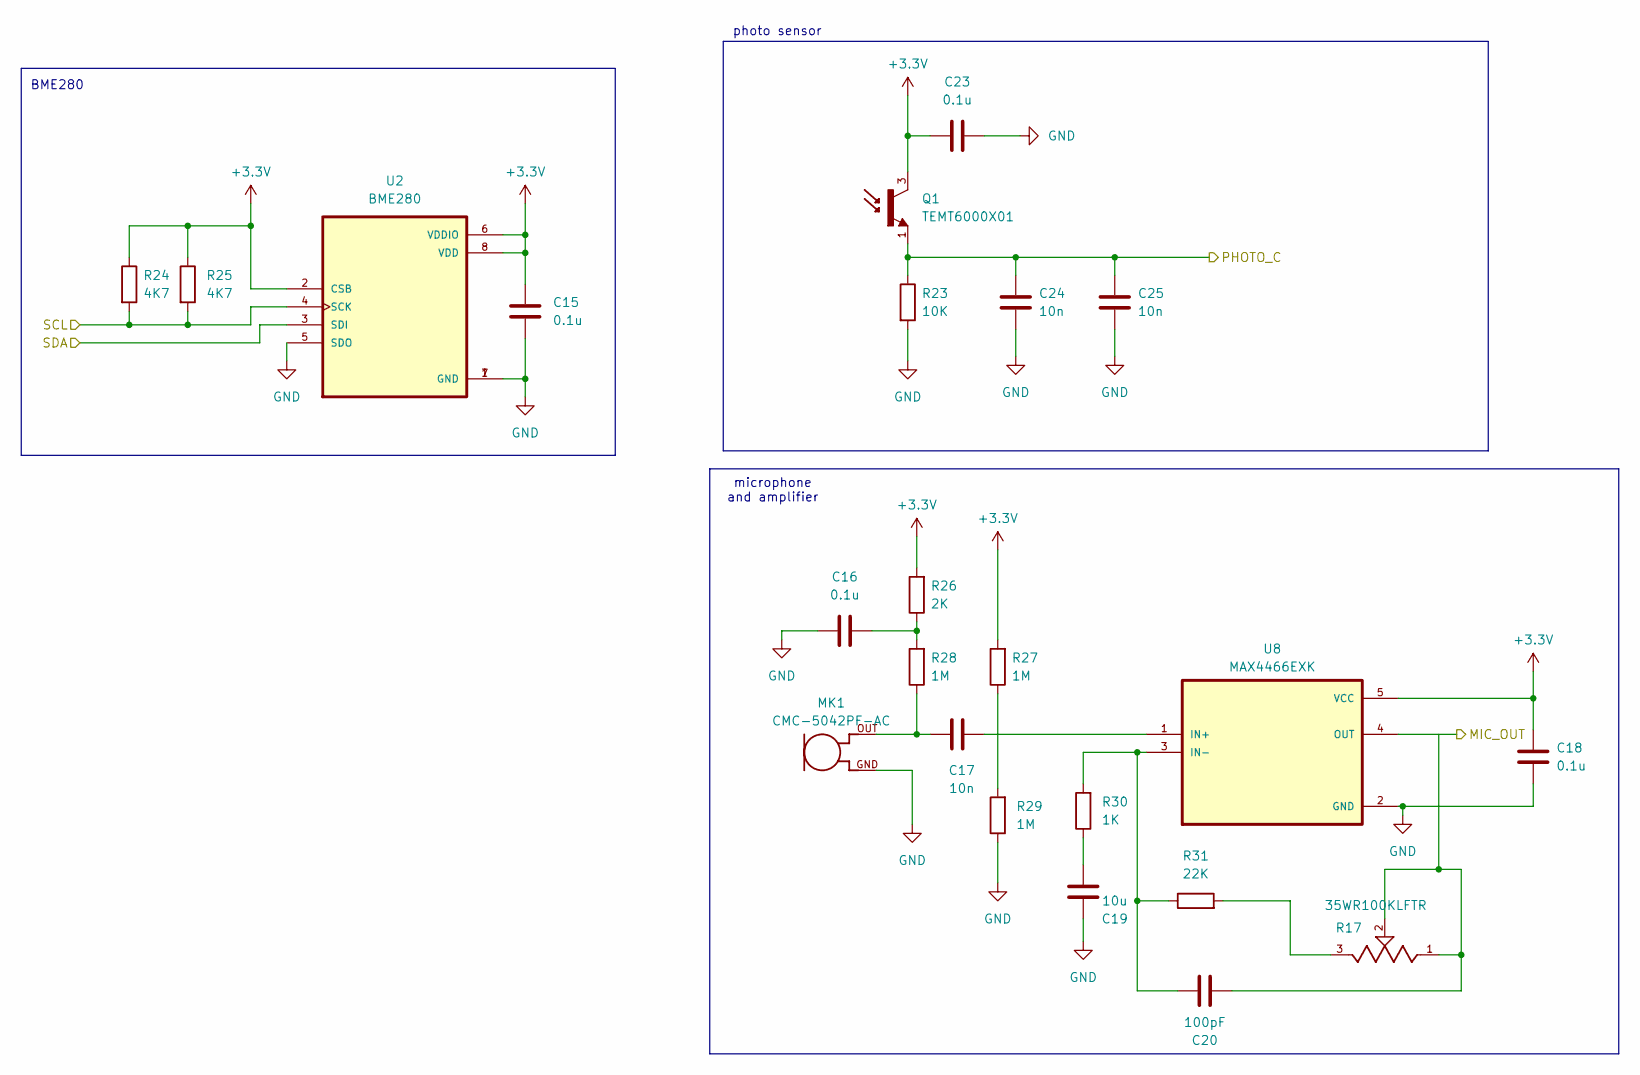
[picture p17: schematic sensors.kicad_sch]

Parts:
C15, C16, C18, C23: 0.1u; C_0805_2012Metric
C17, C24, C25: 10n; C_0805_2012Metric
C19: 10u; C_0805_2012Metric
C20: 100pF; C_0805_2012Metric
MK1: CMC-5042PF-AC; CUI_CMC-5042PF-AC
Q1: TEMT6000X01; TRANS_TEMT6000X01; PARTREV 1.9
R17: 35WR100KLFTR; TRIM_35WR100KLFTR; PARTREV D
R23: 10K; R_0805_2012Metric
R24, R25: 4K7; R_0805_2012Metric
R26: 2K; R_0805_2012Metric
R27, R28, R29: 1M; R_0805_2012Metric
R30: 1K; R_0805_2012Metric
R31: 22K; R_0805_2012Metric
U2: BME280; PSON65P250X250X100-8N
U8: MAX4466EXK; SOT65P210X110-5N

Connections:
+3.3V: C15.1, C18.1, C23.1, Q1.3, R24.1, R25.1, R26.2, R27.2, U2.2 (CSB), U2.6 (VDDIO), U2.8 (VDD), U8.5 (VCC); also elsewhere on the board
/ESP_32_C3_02/MIC_OUT: U8.4 (OUT); also elsewhere on the board
/ESP_32_C3_02/PHOTO_C: C24.2, C25.2, Q1.1, R23.1; also elsewhere on the board
/ESP_32_C3_02/SCL: R24.2, R25.2, U2.4 (SCK); also elsewhere on the board
/ESP_32_C3_02/SDA: U2.3 (SDI); also elsewhere on the board
GND: C15.2, C16.1, C18.2, C19.2, C23.2, C24.1, C25.1, MK1.GND, R23.2, R29.1, U2.1 (GND), U2.5 (SDO), U2.7 (GND), U8.2 (GND); also elsewhere on the board
unnamed: C16.2, R26.1, R28.2
unnamed: C17.1, MK1.OUT, R28.1
unnamed: C19.1, R30.1
unnamed: C20.2, R17.1, R17.2
unnamed: R17.3, R31.2
unnamed: R27.1, R29.2
unnamed: C17.2, U8.1 (IN+)
unnamed: C20.1, R30.2, R31.1, U8.3 (IN-)

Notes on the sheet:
BME280
microphone and amplifier
photo sensor

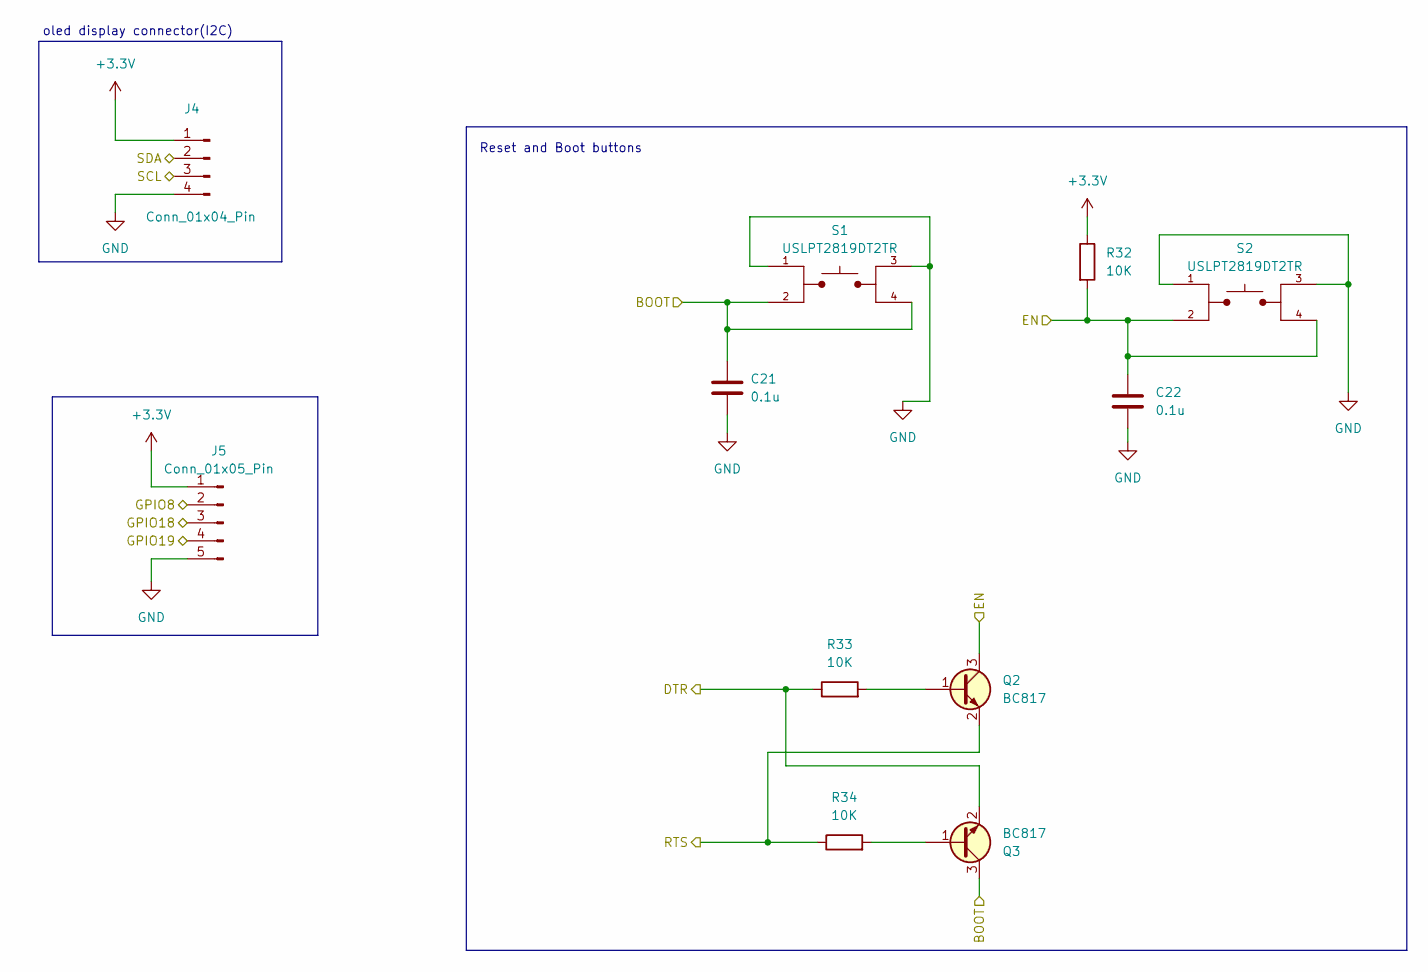
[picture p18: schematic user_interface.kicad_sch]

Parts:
C21, C22: 0.1u; C_0805_2012Metric
J4: Conn_01x04_Pin; PinHeader_1x04_P2.54mm_Vertical
J5: Conn_01x05_Pin; PinHeader_1x05_P2.54mm_Vertical
Q2, Q3: BC817; SOT-23
R32, R33, R34: 10K; R_0805_2012Metric
S1, S2: USLPT2819DT2TR; SW_TL3305AF260QG; PARTREV C

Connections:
+3.3V: J4.1, J5.1, R32.1; also elsewhere on the board
/ESP_32_C3_02/BOOT: C21.1, Q3.3 (C), S1.2, S1.4; also elsewhere on the board
/ESP_32_C3_02/DTR: Q3.2 (E), R33.1
/ESP_32_C3_02/EN: C22.1, Q2.3 (C), R32.2, S2.2, S2.4; also elsewhere on the board
/ESP_32_C3_02/GPIO8: J5.2; also elsewhere on the board
/ESP_32_C3_02/GPIO18: J5.3; also elsewhere on the board
/ESP_32_C3_02/GPIO19: J5.4; also elsewhere on the board
/ESP_32_C3_02/RTS: Q2.2 (E), R34.1; also elsewhere on the board
/ESP_32_C3_02/SCL: J4.3; also elsewhere on the board
/ESP_32_C3_02/SDA: J4.2; also elsewhere on the board
GND: C21.2, C22.2, J4.4, J5.5, S1.1, S1.3, S2.1, S2.3; also elsewhere on the board
unnamed: Q2.1 (B), R33.2
unnamed: Q3.1 (B), R34.2

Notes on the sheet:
Reset and Boot buttons
oled display connector(I2C)

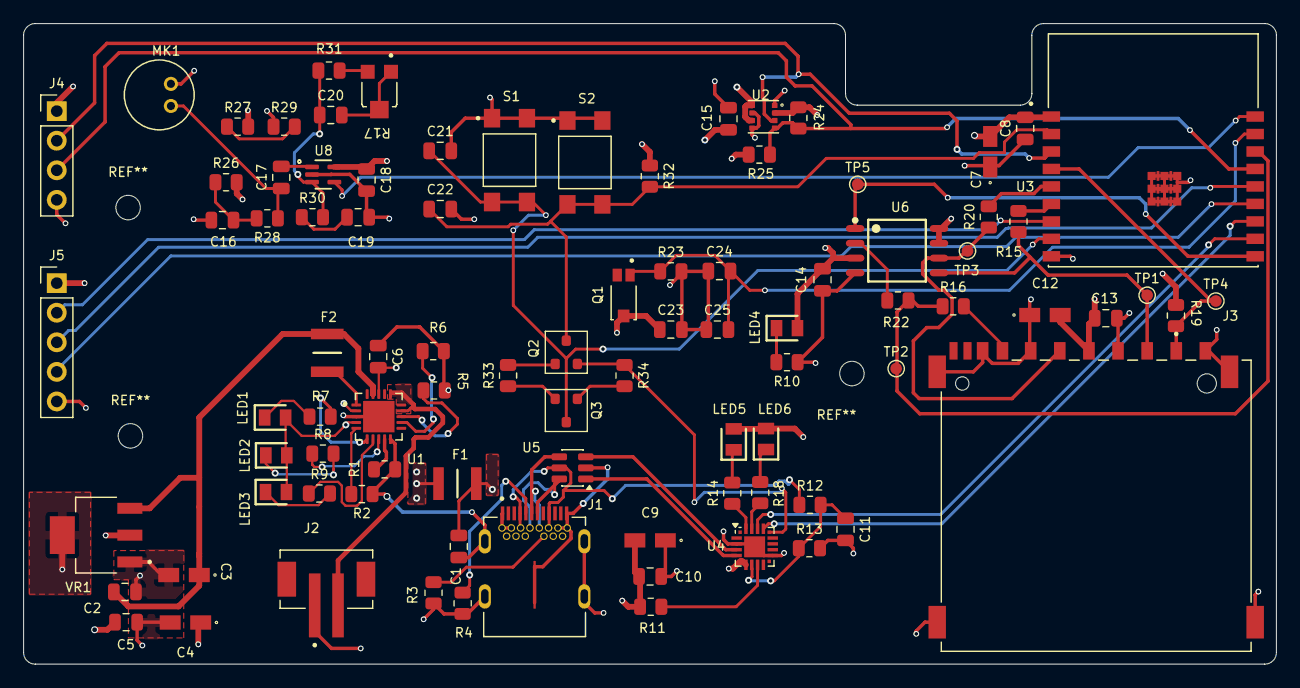
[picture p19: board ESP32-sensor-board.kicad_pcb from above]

Board: 4 copper layers, 107.6 x 55.0 mm, 90 parts (0 on the bottom side), 62 nets.

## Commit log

2026-06-07 ESP32
    ESP32 added to github
    [ESP32-sensor-board-B_Cu.gbl, ESP32-sensor-board-B_Mask.gbs, ESP32-sensor-board-B_Paste.gbp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]
2026-06-07 Initialize README with project overview and features
    Add detailed project description and features for the ESP32-C3 IoT Sensor Board, including PCB design highlights and repository structure.
